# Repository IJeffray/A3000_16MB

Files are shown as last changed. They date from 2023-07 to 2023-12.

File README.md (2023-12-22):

# Acorn A3000 16MB RAM board

December 2023

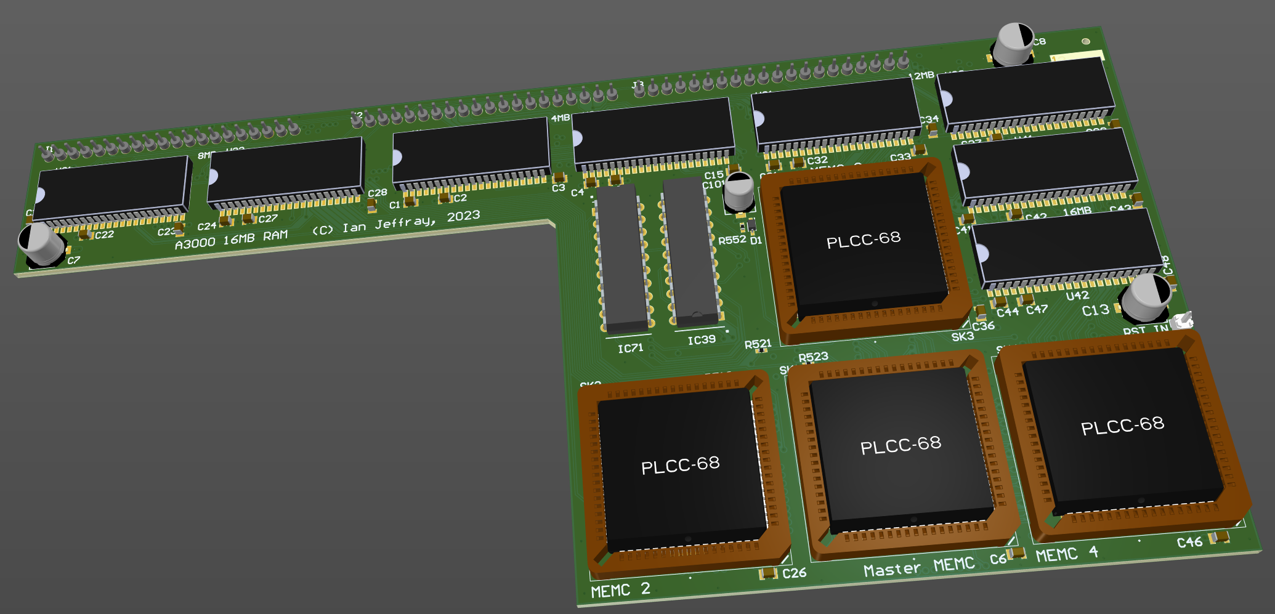
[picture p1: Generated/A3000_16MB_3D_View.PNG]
3D View


A 16MB RAM upgrade for Acorn A3000 machines.  Two PALs (IC39,IC71) are copies of those from the A540.

The first spin of the design has been built and tested, with some design errors and PCB-level errors noted, though proven functional and reliable under regular use and under memory stress test situations.

The updated/corrected design has now been validated and appears reliable.

## Licence

No warranty is provided, and this work is used at your own risk.  

Licenced as CC BY-SA 3.0

Copyright 2023 Ian Jeffray

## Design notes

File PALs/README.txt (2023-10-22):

IC71 and IC39 are direct rips from the same parts on the A540.
Program the .JED files in to Atmel F16V8C-7PU parts

The disassembled .PAL files are just for reference.  Maybe some day this stuff and other bits of the glue logic could all be put in one wee CPLD.

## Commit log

2023-03-17 Initial commit - 'just' needs the glue logic sorting!
    [A3000_16MB.PrjPcb, A3000_16MB.SchDoc, A3000_16MB_M2.SchDoc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]
2023-03-18 Replace CPLD with two PALs as per A540. Add readme and screenshot.
    [A3000_16MB.PrjPcb, A3000_16MB.SchDoc, A3000_16MB_Glue.SchDoc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]
2023-04-10 Corrected abort handling. Removed 3 slave signals not required. Further layout updates. Glue logic remains to be completed.
    [A3000_16MB.SchDoc, A3000_16MB_Glue.SchDoc, A3000_16MB_M2.SchDoc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]
2023-05-31 Correct placement of RAM connector header. Complete routing of glue.
    [A3000_16MB.PrjPcb]
2023-06-02 Correct position of MEMC plug. Improve routing. Place all overlays. First gerber generation.
    [A3000_16MB.PrjPcb]
2023-06-02 Add manufacturing features. Correct outjob for 6 layer board and outline.
2023-06-02 Consolidate BOM. Further layout improvements.
    [A3000_16MB.SchDoc, A3000_16MB_Glue.SchDoc]
2023-06-02 Sort out the resets - sadly means a flying wire to be added, so we can pick up IOC reset, perform the clock synch, then release reset to ARM. IC47 on mainboard needs pin12 lifting and that lifted pin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
    [A3000_16MB.SchDoc, A3000_16MB_Glue.SchDoc]
2023-06-02 Add lots of notes to the glue schematic sheet to describe each section. Fix template and tidy schematic layout.
    [A3000_16MB_Glue.SchDoc]
2023-06-02 Additional schematic clean-up, sheet numbering, outjob.
    [A3000_16MB.PrjPcb, A3000_16MB.SchDoc, A3000_16MB_Glue.SchDoc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]
2023-06-02 Add LCSC part numbers where possible. Add BOM and PnP to Outjob.
    [A3000_16MB.PrjPcb, A3000_16MB.SchDoc, A3000_16MB_Glue.SchDoc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]
2023-06-19 Correct LCSC part number for 10K. Update output job outputs
    [A3000_16MB.PrjPcb, A3000_16MB.SchDoc, A3000_16MB_Glue.SchDoc]
2023-07-02 Correct resets on MEMCs (weren't driven) and VIDRQ/SDRQ/NFLBK which should be using the masked signals to drive the master MEMC. Adjust pad sizes for PALs and tweak board shape, some track layout.
    [A3000_16MB.PrjPcb, A3000_16MB.SchDoc, A3000_16MB_Glue.SchDoc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]
2023-07-03 Correct footprint for PLCC64 plug - caused lots of re-routing. Remove pointless BANK resistor. Further layout tweaks and cleanup including tenting all vias to match JLCPCB spec.
    [A3000_16MB.PrjPcb, A3000_16MB.SchDoc, Acorn.PcbLib]
2023-11-01 Tweak settings for JLCPCB outputs
    [A3000_16MB.PrjPcb]
